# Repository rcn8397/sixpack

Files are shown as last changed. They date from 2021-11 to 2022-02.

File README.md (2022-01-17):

# sixpack
Six-Pack Cherry MX Macro Pad

# Layout
Six Switch MX Layout

# Plate & Case

 * Switch Type: MX {_t:3}
 * Stabilizer Type: Cherry + Costar {_s:1}
 * Case Type: Sandwich
 * USB Cutout: On
   * Location: 0 (default)
   * Width: 12
 * Mount Holes: 4, 3, 8
 * Edge Padding: On, 10,10,10,10 (W,N,E,S)
 * Plate Corners: On, 4
 * Custom Polygons: Off
 * Kerf: Off
 * Key Unit Size: Off
 * Line Color: Off
 * Line Weight: Off

## 3D Printing
The plate and case are also hosted on [prusaprinters.org](https://www.prusaprinters.org/prints/113097-sixpack)

### Openscad
Each layer can be generated/customized using openscads customizer. 

### Slicing
I use Cura to slice, but I suspect any slicer will work. 

* Nozzle: 0.4mm
* Layer Height: 0.2mm
* Supports: No

# QMK
## Setup
## Compiling
Compile the code using QMK

     qmk compile -kb handwired/sixpack  -km default
     
## Flashing
Flash the target (ProMicro), note you must hit the reset switch to enter bootloader.

     qmk flash -kb handwired/sixpack  -km default
     
### Linux Issues
On Ubuntu 18.04 I needed to stop the ModemManger service to communicate with ttyACM0 serial device. 

    sudo systemctl stop ModemManager.service
    sudo systemctl disable ModemManager.service
    
 ## Customization
 TODO

# Resources
 * https://www.youtube.com/watch?v=IKe_hrvYH1M
 * http://www.keyboard-layout-editor.com/
 * http://builder.swillkb.com/
 * https://wiki.ai03.com/books/pcb-design/chapter/pcb-designer-guide
 * https://matt3o.com/hand-wiring-a-custom-keyboard/

## QMK
 * https://docs.qmk.fm/#/
 * https://docs.qmk.fm/#/hand_wire
 * Sixpack firmware (QMK forked) https://github.com/rcn8397/qmk_firmware/tree/personal/nordeen%2Fsixpack
 * Work flow https://docs.qmk.fm/#/newbs_git_using_your_master_branch

### QMK Git Workflow/Setup
Add the forked repo as a remote

      git remote add myfork git@github.com:rcn8397/qmk_firmware.git
      
Next verify the forked repo was added

      git remote -v
      
Should look something like:

      myfork	git@github.com:rcn8397/qmk_firmware.git (fetch)
      myfork	git@github.com:rcn8397/qmk_firmware.git (push)
      origin	https://github.com/qmk/qmk_firmware.git (fetch)
      origin	https://github.com/qmk/qmk_firmware.git (push)
      
Next push the development branch to the fork and track it.

      git push -u myfork

## Promicro
 * https://deskthority.net/wiki/Arduino_Pro_Micro#Pinout
 * https://golem.hu/guide/pro-micro-upgrade/
 * https://learn.sparkfun.com/tutorials/pro-micro--fio-v3-hookup-guide/troubleshooting-and-faq#ts-reset

## Atmega32u4 Data sheet

 * http://ww1.microchip.com/downloads/en/devicedoc/atmel-7766-8-bit-avr-atmega16u4-32u4_datasheet.pdf

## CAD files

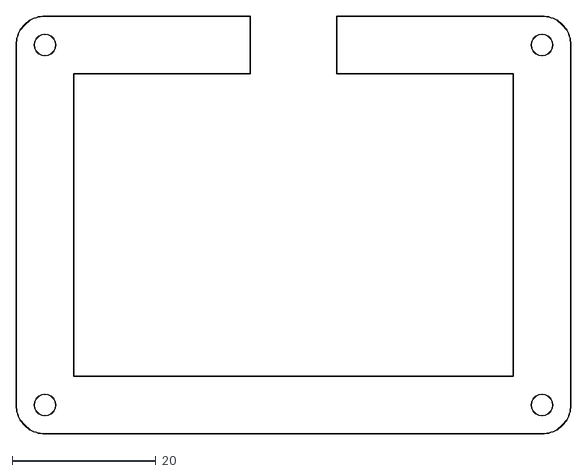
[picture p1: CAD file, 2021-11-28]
mechanical/open.dxf
77.2 x 58.1

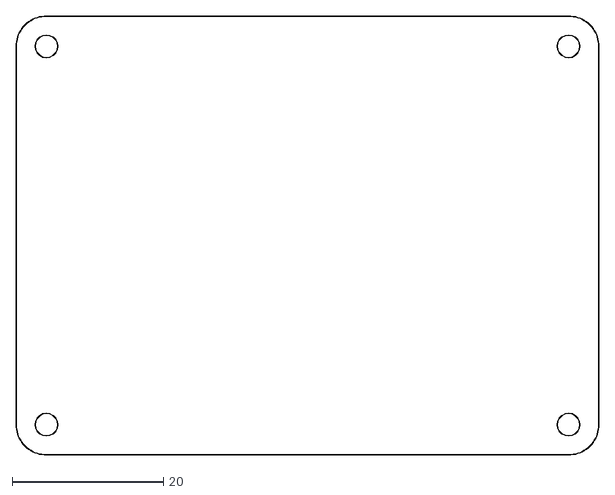
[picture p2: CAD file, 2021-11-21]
mechanical/bottom.dxf
77.2 x 58.1

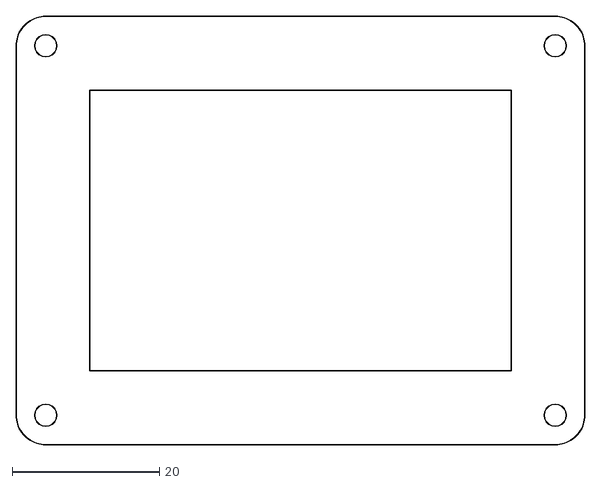
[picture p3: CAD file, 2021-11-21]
mechanical/top.dxf
77.2 x 58.1

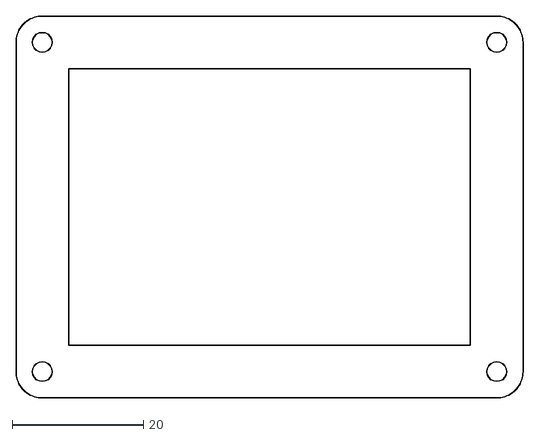
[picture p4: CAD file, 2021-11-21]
mechanical/closed.dxf
77.2 x 58.1

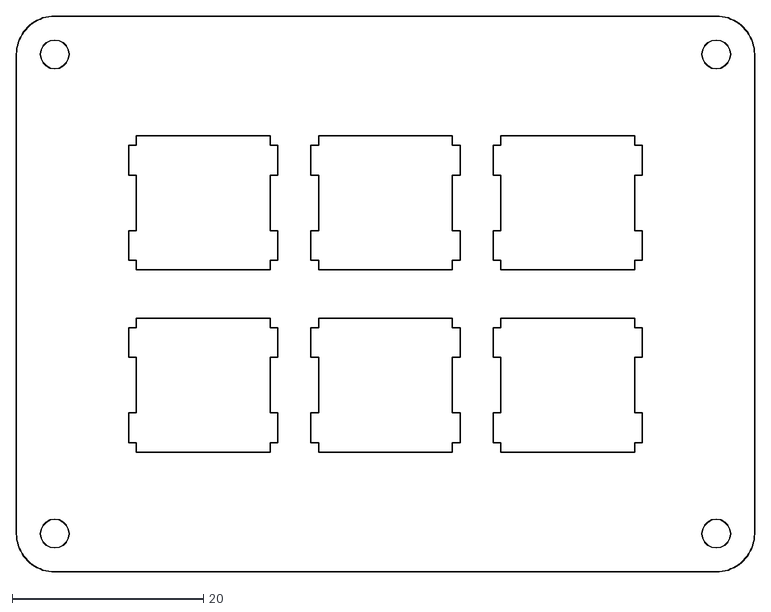
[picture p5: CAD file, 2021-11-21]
mechanical/switch.dxf
77.2 x 58.1

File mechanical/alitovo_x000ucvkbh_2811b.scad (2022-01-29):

///< Alitovo Neo pixel RGB X000UCVKBH 2812b-1-LED-WH


///< Parameters - Begin
$fn = 60;

///< Package size
led_assembly_h = 2.8;
led_assembly_d = 9.6;
package_h = 2.8;
package_d = 9.6;

///< Diameter of the PCB 
pcb_d = 9.6;
pcb_h = 1.2;

///< Demensions of the LED IC
led_w = 5;
led_d = led_w;
led_h = led_assembly_h - pcb_h;

solder_pad_w = 2.5;
solder_pad_d = 1.5;
solder_pad_h = 50; //< Large as the value isn't passed into neopixel

num_leds = 3;
padding  = 1;
left_padding = 1;
right_padding = 1;
lpad_channeled = true;
rpad_channeled = true;
tolerance      = 0.5;


include_solder_pads = true;
use_hulled_pads     = true;
use_all_pads_hulled = false;
use_as_jig          = false;

///< Modules
module pcb(h = pcb_h, d = pcb_d){
     ///< LED PCB definition
     ///< The h/d parameters are passed in to
     ///< allow for socketing of the LEDs.
    color( "white" )cylinder( h=h, d=d, center = true, $fn = 30 );
}

module led(){
     ///< Neo pixel LED (2812b-1)
     union(){
         color( "silver" )cube( [ led_w, led_d, led_h ], center = true );
         color( "lime" )
             cylinder( h=led_h, d= led_w, center = true, $fn = 30 );
         }
}

module solder_pad(){
    cube( [ solder_pad_w, solder_pad_d, solder_pad_h ], center = true );
}

module solder_pads(){
     translate([1+solder_pad_w/2,0,-solder_pad_h/2])
         solder_pad();
     translate([1+solder_pad_w/2,2,-solder_pad_h/2])
         solder_pad();
     translate([1+solder_pad_w/2,-2,-solder_pad_h/2])
         solder_pad();
}

module solder_pads_mirrored(){
     solder_pads();
     mirror([1,0,0])
         solder_pads();
}

module hulled_pads(){
    hull(){
        solder_pads();
    }
}

module hulled_pads_mirrored(){
    hulled_pads();
     mirror([1,0,0])
         hulled_pads();
}

module all_pads_hulled(){
    hull(){ hulled_pads_mirrored(); }
}

module neo_pixel(h=pcb_h, d=pcb_d ){
     ///< Assembly of the led and pcb_pad
     union(){
         translate([0,0,h-0.01])led();
          pcb(h=h, d=d);
          }
     if( include_solder_pads ){
         solder_pads_mirrored();
         if( use_hulled_pads ){
             if( use_all_pads_hulled ){
                 all_pads_hulled();
             } else {
                 hulled_pads_mirrored();
             }
         } else {
             solder_pads_mirrored();
         }
     }
}

module pixel_iter( num_pixels = 1, pad = 1, tol = 0.55, jig_h = 0 ){
    //< PCBs
    cylinder_d = pcb_d+tol;
    cylinder_h = package_h+jig_h;

    origin = pad/2 + cylinder_d/2;
    translate([origin,0,0] ){
        for( i = [ 0 : num_pixels-1 ] ){
            x = (i * (pad + cylinder_d) );
            translate([x, 0, pad ])
                cylinder( h = cylinder_h, d = cylinder_d, center = true );
            translate([x, 0, 0 ])
                neo_pixel();
        }
    }
}

///< Calculate the cubes width given N pixels with a P pad and T tolerance
function cube_w( n = 1, p = 1, t = 0.5 ) = ( ( (n+1)*p ) + (n*pcb_d) + (t*n-1));

module cube_iter( num_pixels = 1, pad = 1, tol = 0.5, channeled = true ){
    //< Cube that acts as the housing for the led
    cube_d = pcb_d+pad*2;
    cube_h = package_h+pad;
    w = cube_w(num_pixels, pad, tol );
    translate([ w/2, 0, 0] ){
        difference(){
            color("lime")cube([w, cube_d, cube_h], center=true );
            if( channeled ){
                translate( [0,0,pad] )
                    #cube( [ w , pcb_d/2, package_h ],center=true );
            }
        }
    }
}

module pixel_strip(
                   num_pixels   = 3,
                   pad          = 1,
                   lpad         = 1,
                   lpad_channel = true,
                   rpad         = 1,
                   rpad_channel = true,
                   tol          = 0.5,
                   is_jig       = false,
                   ){
    lpad_w = cube_w( lpad, pad, tol );
    mpad_w = cube_w( num_pixels+lpad, pad, tol );
    rpad_w = cube_w( num_pixels+lpad+rpad, pad, tol );

    cube_iter( lpad, pad, tol, lpad_channel );
    translate( [ lpad_w, 0, 0 ] ){
        difference(){
            cube_iter( num_pixels, pad, tol, channeled = true );
            if( is_jig ){
                #pixel_iter( num_pixels, pad = pad, tol, jig_h = package_h+2*pad );
            } else {
                #pixel_iter( num_pixels, pad = pad, tol );
            }
        }
    }
    translate( [mpad_w, 0, 0 ])
        cube_iter( rpad, pad, tol, rpad_channel );
}

///< Build object
///< Remove this when including

//neo_pixel();

pixel_strip(
            num_pixels   = num_leds,
            pad          = padding,
            lpad         = left_padding,
            lpad_channel = lpad_channeled,
            rpad         = right_padding,
            rpad_channel = rpad_channeled,
            tol          = tolerance,
            is_jig       = use_as_jig,
            );

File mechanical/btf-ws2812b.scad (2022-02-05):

use <sixpack.scad>

/*
Module: WS2812B LED strip
BTF Lighting WS2812b 5050smd LED 3.3ft 144 (2x72) pixel strips
https://www.amazon.com/gp/product/B01CDTEJR0/

https://cdn-shop.adafruit.com/datasheets/WS2812.pdf
*/

/*
Parameters
*/

// Finish/Quality
$fn = 90; // [0:90:120]

// Number of LEDs in the strip
num_leds  = 6; // [0:1:72]

// Pitch of the LEDs
led_pitch = 1.92; // [0:0.01:25]

// Channel thickness
channel_t = 1.0; // [0:1:5]
// Channel X
channel_x = 22; // [0:0.1:50]


///< Parameters after this are hidden from the customizer
module __Customizer_Limit__(){}

// WS2812B
ws2812b_w = 5.0;
ws2812b_d = 5.0;
ws2812b_h = 1.57;

// Strip Width
strip_d = 12;   // [0:0.01:15]
strip_h = 2.13 - ws2812b_h; // [0:0.01:5]


///< Modules
module ws2812b(center = true){
    color("white")cube( [ws2812b_w, ws2812b_d, ws2812b_h], center = center );
    color("yellow")cylinder( h = ws2812b_h, d = ws2812b_w*0.90, center = center );
}


function ribbon_w( n = 1, p = 1 ) = ( (n+1)*p ) + (n*ws2812b_w) ;

module strip( n = num_leds, pitch = 1, center = true ){
    
    for( i = [0:n-1] ){
        x = i * ( pitch + ws2812b_w );
        translate([x,0,0])
            ws2812b(center);
    }
    strip_w = ribbon_w(n, pitch);
    adjust  = strip_w/2 - ws2812b_w;
    translate([ adjust, 0, -ws2812b_h/2 ] )
        color("black")cube( [ strip_w, strip_d, strip_h ], center = center );
}

module channel( n = num_leds, pitch = 1, thickness = channel_t, center = true ){
    d = strip_d + thickness;
    for( i = [0:n-1] ){
        x = i * ( pitch + ws2812b_w );
        translate( [x,d/2,-thickness/2] )
            cylinder( h = ws2812b_h+thickness, d = ws2812b_w/2, center );
        translate( [x,-d/2,-thickness/2] )
            cylinder( h = ws2812b_h+thickness, d = ws2812b_w/2, center );

    }
    channel_w = ribbon_w( n, pitch );
    adjust = channel_w/2 - ws2812b_w;
    translate( [ adjust, 0, 0 ] )
        color("cyan")cube( [ channel_w, d, thickness ], center );
    
}
///< Build object

dxf( "closed.dxf", height = 2.13+channel_t );

difference(){
translate([channel_x, 44.47, channel_t/2 ] )channel( num_leds, led_pitch );
#translate([channel_x, 44.47, 2.13/2+channel_t ] )strip(num_leds, led_pitch);
}

difference(){
translate([channel_x, 14.35, channel_t/2 ] )channel( num_leds, led_pitch );
#translate([channel_x, 14.35, 2.13/2+channel_t ] )strip(num_leds, led_pitch);
}

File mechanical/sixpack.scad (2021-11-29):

///< Object definition
/*
Six Pack Cherry MX macro pad
Author Ryan Nordeen
*/

/*
Parameters
*/
$fn=90;
fname = "switch.dxf"; // [ switch.dxf, open.dxf, closed.dxf, top.dxf, bottom.dxf ]

///< Parameters after this are hidden from the customizer
module __Customizer_Limit__(){}
// Plate heights
switch_h   = 1.5; // [0:0.1:10]
closed_h   = 4.0; // [0:0.1:10]
open_h     = 7.0; // [0:0.1:10]
bottom_h   = 5.0; // [0:0.1:10]

// Plate and case sandwich
case_x       = 77.152; // mm
case_y       = 58.102; // mm
cut_l        = 675.565; // mm Cut path length
case_pad     = 4.0;
counter_sink = -2.0;
sink_d1       = 6.0;
sink_d2       = 4.5;
mounting_holes = [
                  [case_pad,        case_pad+0.5,            counter_sink ],
                  [case_pad,        case_y-case_pad+0.5, counter_sink ],
                  [case_x-case_pad, case_y-case_pad+0.5,     counter_sink ],
                  [case_x-case_pad, case_pad+0.5,            counter_sink ],
                  ];


// HiLetGo Pro Micro Clone
// https://www.amazon.com/gp/product/B01MTU9GOB/ref=ppx_yo_dt_b_asin_title_o00_s01?ie=UTF8&psc=1
// Item Dimensions
promicro_d = 34.00;
promicro_w = 18.50; // 18.04 ish
promicro_h = 4.00;
promicro_pad = 1.0;
usb_x      = 8.0;
usb_y      = 6.0;
usb_z      = 4.0;

///< Rst Btn dimensions
btn_x      = 6.5;
btn_y      = 6.5;
btn_z      = 5.0;
btn_d      = 4.0;


///< Modules
module pushbtn( tol = 0 ){
    btn_h = btn_z;
    color( "black" )cube( [btn_x+tol,btn_y+tol,btn_z+tol], true );
    translate([0,0,-btn_h])
        color( "silver" )
        cylinder( h=btn_h, d=btn_d, center = true, $fn=90 );
}

module promicro( tol = 0 ){
    color("green")
        cube( [ promicro_w+tol, promicro_d+tol, promicro_h+tol ], true );
    if( tol == 0 ){
        translate( [ 0, promicro_d/2, 0 ] )
            color("silver")
            cube( [ usb_x, usb_y, usb_z ], true );
    }
}

module counter_sinks(){
    for( p = mounting_holes ){
        translate( p )
            color("pink")
            #cylinder( h = bottom_h, d1 = sink_d1, d2 = sink_d2, true );
    }
}

module dxf( f, height ){
    echo( "DXF: ", f, "Height: ", height );
    linear_extrude( height )
        import( f );//center = false, dpi= 96);
}

///< Build object
if( ( fname == "closed.dxf" ) ){
    dxf( fname, closed_h );
 } else if( ( fname == "open.dxf") ) {
    dxf( fname, open_h );
 } else if( ( fname == "bottom.dxf" ) ) {
    translate( [ case_x/2, case_y/2, bottom_h+1, ] )
        difference(){
        promicro(promicro_pad);
        translate([0,0,1])
            promicro();
    }
    difference(){
        dxf( fname, bottom_h );
        translate( [ case_x/4, case_y/4, bottom_h-1 ] )
            #pushbtn();
        counter_sinks();
    }
 } else {
    dxf(fname, switch_h );
 }

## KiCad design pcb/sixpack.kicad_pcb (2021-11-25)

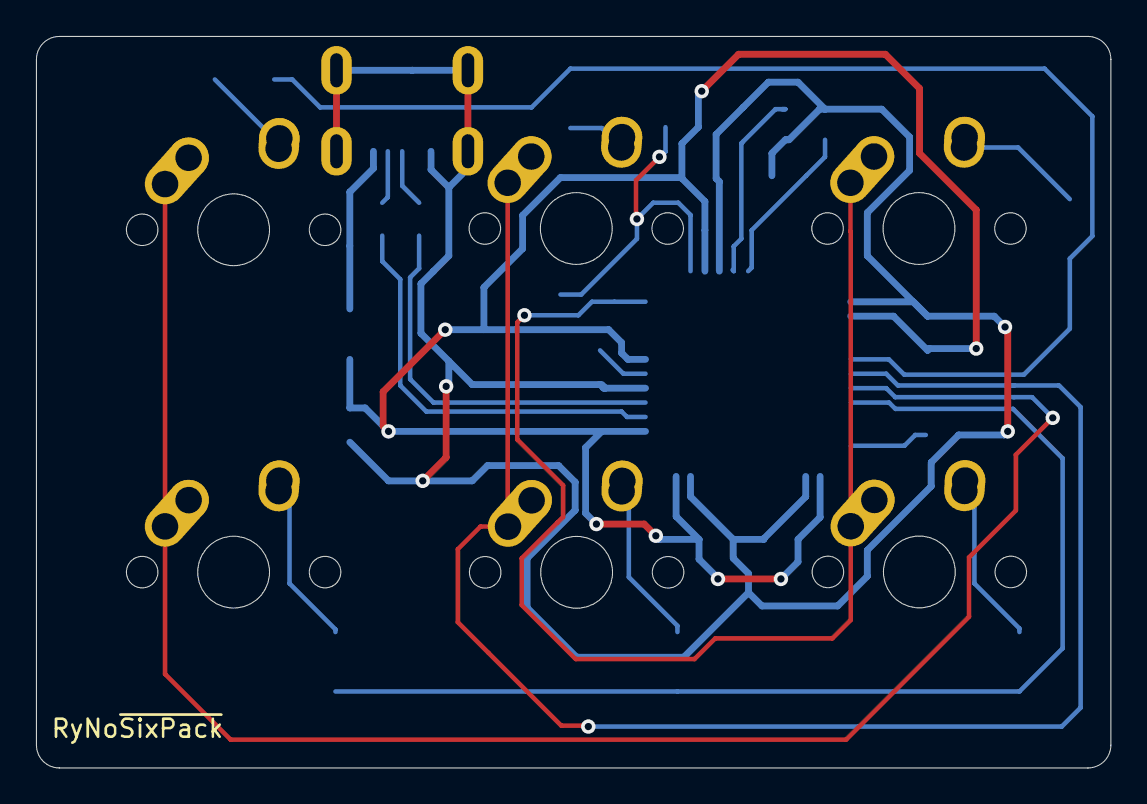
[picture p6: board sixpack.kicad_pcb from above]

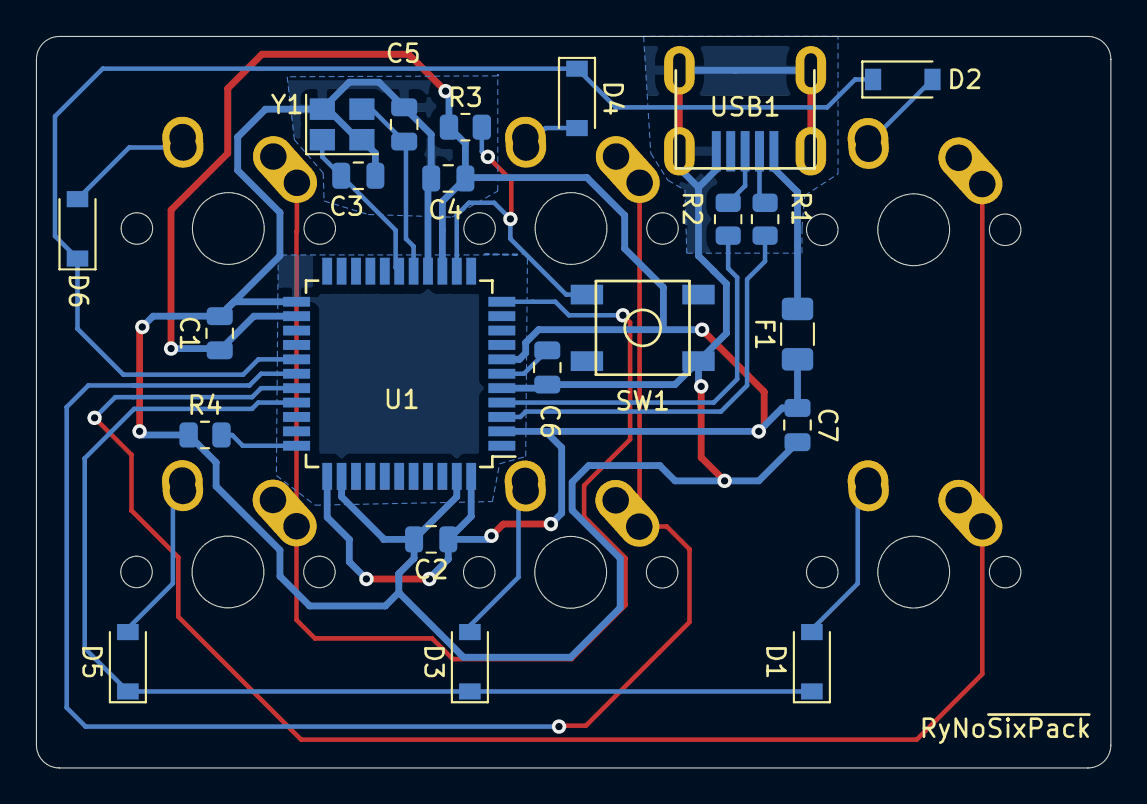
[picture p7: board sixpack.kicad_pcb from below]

Board: 2 copper layers, 59.7 x 40.6 mm, 28 parts (22 on the bottom side), 23 nets.

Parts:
C1, C2, C4: 0.1uF; C_0805_2012Metric
C3, C5: 22pF; C_0805_2012Metric
C6: 1uF; C_0805_2012Metric
C7: 10uF; C_0805_2012Metric
D1, D2, D3, D4, D5, D6: SOD-123; D_SOD-123
F1: 500mA; Fuse_1206_3216Metric
MX1, MX2, MX3, MX4, MX5, MX6: MX-NoLED; MX-1U-NoLED
R1, R2: 22; R_0805_2012Metric
R3, R4: 10k; R_0805_2012Metric
SW1: SW_Push; SKQG-1155865
U1: ATmega32U4-AU; TQFP-44_10x10mm_P0.8mm
USB1: Molex-0548190589
Y1: 16MHz; Crystal_SMD_3225-4Pin_3.2x2.5mm

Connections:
+5V: C1.1, C2.1, C4.1, C7.1, F1.1, R3.1, U1.2, U1.7, U1.14, U1.24, U1.34, U1.44
COL0: MX1.1, MX2.1, U1.29
COL1: MX3.1, MX4.1, U1.28
COL2: MX5.1, MX6.1, U1.11
D+: R2.2, USB1.3
D-: R1.2, USB1.4
GND: C1.2, C2.2, C3.2, C4.2, C5.2, C6.2, C7.2, R4.1, SW1.1, U1.5, U1.15, U1.23, U1.35, U1.43, USB1.1, USB1.6, Y1.2, Y1.4
unnamed: C3.1, U1.17, Y1.1
unnamed: C5.1, U1.16, Y1.3
unnamed: C6.1, U1.6
unnamed: D1.2, MX1.2
unnamed: D2.2, MX2.2
unnamed: D3.2, MX3.2
unnamed: D4.2, MX4.2
unnamed: D5.2, MX5.2
unnamed: D6.2, MX6.2
unnamed: R1.1, U1.3
unnamed: R2.1, U1.4
unnamed: R3.2, SW1.2, U1.13
unnamed: R4.2, U1.33
ROW0: D2.1, D4.1, D6.1, U1.27
ROW1: D1.1, D3.1, D5.1, U1.30
VCC: F1.2, USB1.5

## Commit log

2021-11-14 SVG was not working, switched to dxf
    [bottom.dxf, closed.dxf, open.dxf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]
2021-11-14 Changed to 1.5 height
    [sixpack.scad]
2021-11-14 PCB design guide started
    [sixpack.kicad_pcb, sixpack.sch]
2021-11-14 Adding submodules for kicad libraries
2021-11-15 Atmega32u4 schemtaic
    [sixpack.sch]
2021-11-15 Added USB molex connection and six pack switch matrix.
    [sixpack.sch]
2021-11-15 Assigned foot prints
    [sixpack.sch]
2021-11-21 Decided on simple six pack layout
    [bottom.dxf, closed.dxf, open.dxf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]
2021-11-24 finished routing
    [sixpack.kicad_pcb]
2021-11-24 moved 10uF to after the polyfuse
    [sixpack.kicad_pcb]
2021-11-25 connected usb ground pads and shrunk gnd plane
    [sixpack.kicad_pcb]
2021-11-25 Added Gerbers
    [sixpack-B_Cu.gbl, sixpack-B_Mask.gbs, sixpack-B_SilkS.gbo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]
2021-11-25 Moved labels
    [sixpack.kicad_pcb]
2021-11-28 Mech updates, adding promicro and rst button
    [open.dxf, sixpack.scad]
2021-11-28 promicro fits
    [sixpack.scad]
2021-11-29 bottom printed well and parts fit
    [sixpack.scad]
2022-01-23 Crafting neopixel tools
    [neo_pixel.scad]
2022-01-23 hulled variant
    [neo_pixel.scad]
2022-01-25 strip seems possible
    [neo_pixel.scad]
2022-01-25 channel is now apart of the cube_iter
    [neo_pixel.scad]
2022-01-25 jig created
    [neo_pixel.scad]
2022-01-29 Trimming neo_pixel.scad
    [neo_pixel.scad]
2022-01-29 Renamed neo_pixel to alitovo brand device
    [alitovo_x000ucvkbh_2811b.scad]
2022-01-29 renamed scad to led_layer
    [led_layer.scad]
2022-02-01 starting to place ribbon strips
    [btf-ws2812b.scad]
2022-02-05 working led layer
    [btf-ws2812b.scad]
